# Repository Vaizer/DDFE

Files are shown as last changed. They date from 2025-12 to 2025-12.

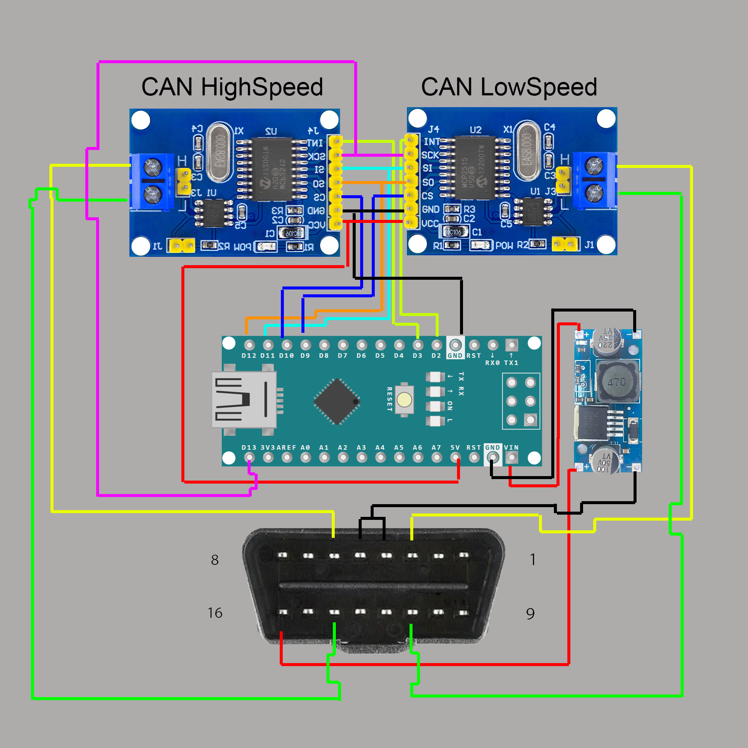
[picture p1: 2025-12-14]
Scheme/Scheme.png

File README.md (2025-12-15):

# DIM's Display Function Extender 
Device for output diagnostic parameters on Volvo P2 dashboard's (DIM) display.\
Using library https://github.com/coryjfowler/MCP_CAN_lib from Cory J Fowler, big thanks for a lot of useful materials to https://github.com/vtl and Volvo-DDD project.

Included sketch mainly aims pre-facelift models (-2004), but all accumulated informartion about other MY are included in sketch for you to try!\
Set up for 2001 Volvo V70XC with B5244T engine and automatic transmission, should work without changes on same configuration (confirmed to work also on B5234T and year 2000 V70).

Pre-facelift cars (-2004) would need getting second OBD2 (or any other) connector **WITH** CAN-L and CAN-H from CEM or it will not work!\
Facelift cars already have CANs on OBD2. Instructions for connecting second OBD2 and device assebly are also included.  \
For now **MY2003-2004 is not guaranteed to work** as I don't have correct IDs or cars to check if it will work with 2002 or other IDs.\
**2000, 2001, 2002, 2005+ tested.**

14 АТФ_Т_найс

## Current supported readouts:
**Engine (ECM):**
- Atmospheric pressure
- Boost pressure
- Intake air temperature
- Mass airflow 
- Battery voltage
- Coolant temperature
- AC pressure
- Speed (kmh)
- Idle fuel trim
- Long-term fuel trim (LTFT) (Low)
- Long-term fuel trim (LTFT) (High)
- Short-term fuel trim (STFT)
- Misfire counter

**Gearbox (TCM):**
- ATF temperature

**Other sensors could be added through getting commands from VIDA log file and DB.**

25 итог

## Controls:
- Short press RESET: changing current parameter (page)
- Long press RESET: disabling output from DDFE on screen (to use display an intended)
Screen enables on short press

## Hardware used:
- Arduino Nano
- 2x MCP2515
- DC-DC converter (12v to 5v)
- OBD2 connector (optional)

## More info about project on my Drive2:
- https://www.drive2.ru/l/712830156913249071/
- https://www.drive2.ru/l/717368116278996470/
- https://www.drive2.ru/l/721407721999439468/

Also check Volvo-P2-informer by drPioneer, inspired by my project: https://github.com/drpioneer/Volvo-P2-informer </br> Same hardware, sketch for facelift models (XC90 2011)

Volvo-DDD by vtl: https://github.com/vtl/volvo-ddd

Not a native english-speaker, not a programmer - sorry for mistakes.

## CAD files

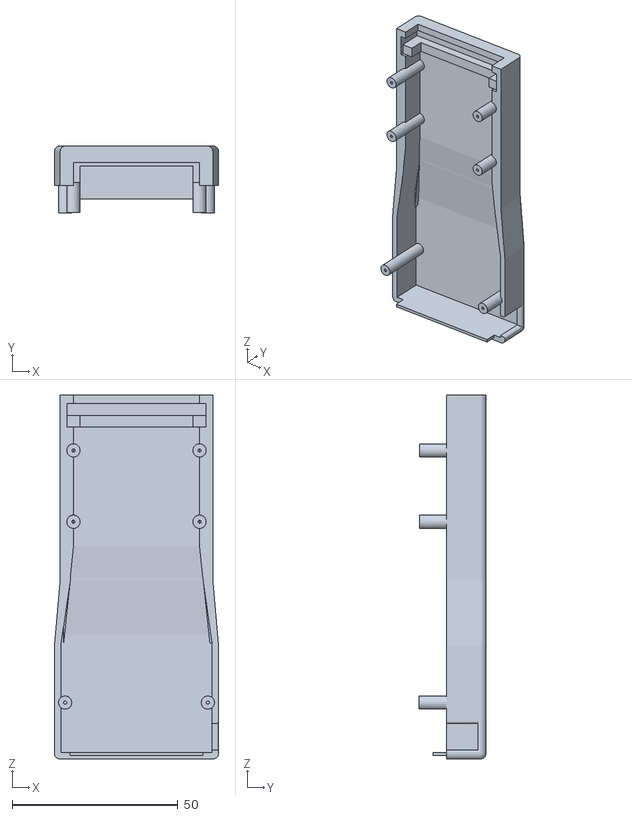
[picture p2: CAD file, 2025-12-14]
Case (3D model)/DDFE_1_2.stl
49.5 x 20.3 x 109.7

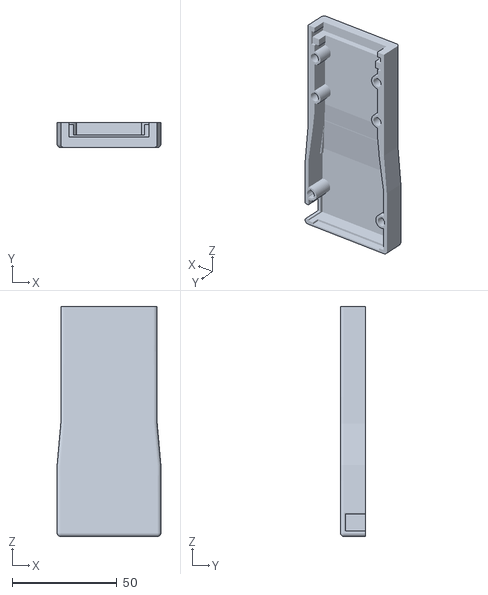
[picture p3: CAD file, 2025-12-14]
Case (3D model)/DDFE_2.stl
49.5 x 12.0 x 109.7

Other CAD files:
Case (3D model)/DDFE_1_1.stl

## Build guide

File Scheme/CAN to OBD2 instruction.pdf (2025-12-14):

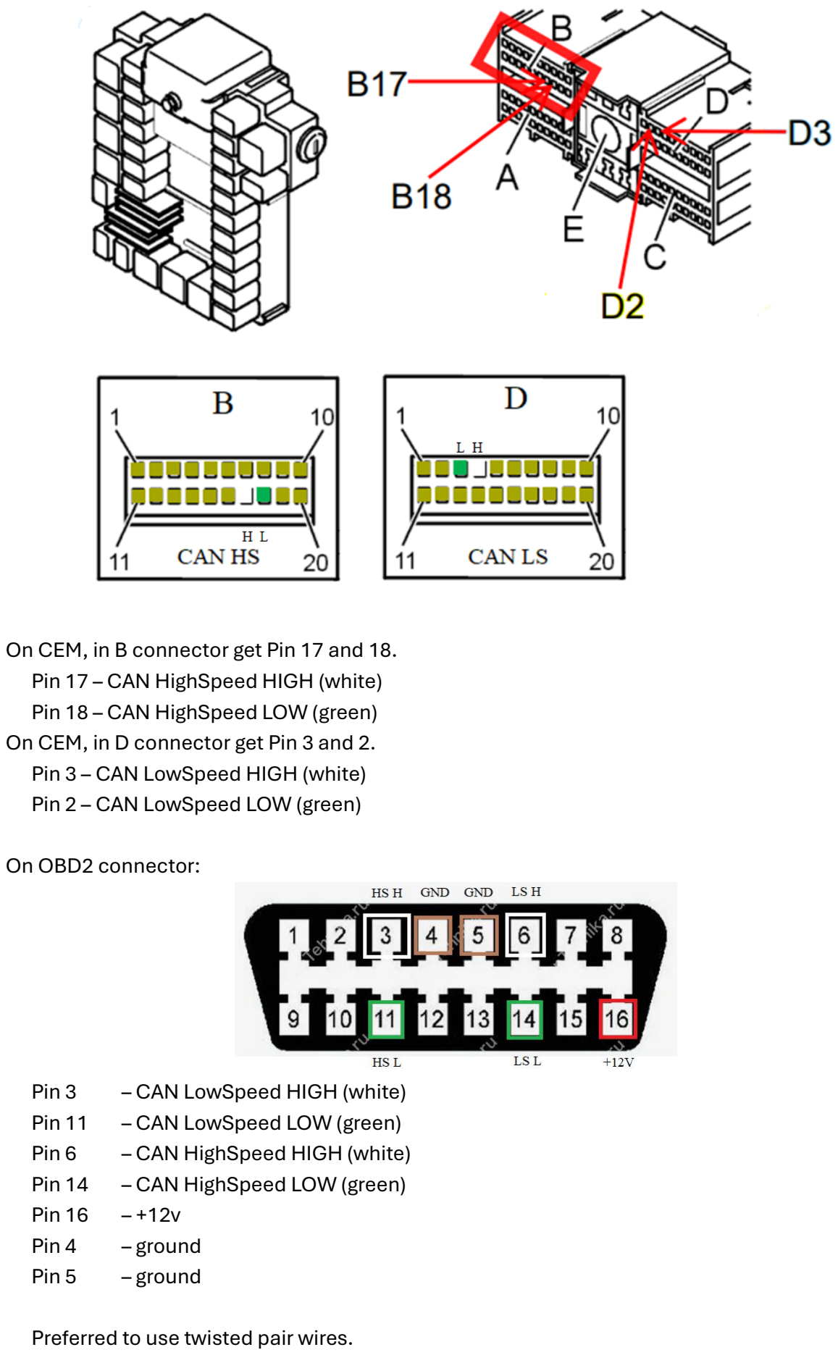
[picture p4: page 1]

On CEM, in B connector get Pin 17 and 18. Pin 17 – CAN HighSpeed HIGH (white) Pin 18 – CAN HighSpeed LOW (green) On CEM, in D connector get Pin 3 and 2. Pin 3 – CAN LowSpeed HIGH (white) Pin 2 – CAN LowSpeed LOW (green)

On OBD2 connector:

Pin 3 | – CAN LowSpeed HIGH (white)
Pin 11 | – CAN LowSpeed LOW (green)
Pin 6 | – CAN HighSpeed HIGH (white)
Pin 14 | – CAN HighSpeed LOW (green)
Pin 16 | – +12v
Pin 4 | – ground
Pin 5 | – ground

Preferred to use twisted pair wires.

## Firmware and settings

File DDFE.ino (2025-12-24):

#include <SPI.h>
#include "mcp_can.h"

// Обозначаем пины подключения CS и INT на шильдах к ардуине к HighSpeed и LowSpeed CAN соответственно
#define CAN_HS_CS_PIN 10
#define CAN_HS_INT    3

#define CAN_LS_CS_PIN 9
#define CAN_LS_INT    2

// Прописываем скорость работы CAN и частоте работы для MCP
#define CAN_HS_SPEED  CAN_250KBPS // Скорость CAN HS для дореста
//#define CAN_HS_SPEED  CAN_500KBPS // Скорость CAN HS для реста 
#define CAN_LS_SPEED  CAN_125KBPS // Скорость CAN LS 

#define MCP_HZ        MCP_16MHZ   // Если частота работы MCP 16MHZ
//#define MCP_HZ        MCP_8MHZ	// Если частота работы MCP 8MHZ

// Прописываем используемые ID (2001г)
#define DIAG_ID     0x000FFFFEUL  // Диагностический id 
#define PHM_ID      0x00400008UL  // id модуля телефона (PHM) (2001)
#define LCD_ID      0x00C0200EUL  // id управления экраном DIM (2001)
#define L_SWITCH_ID 0x8111300AUL  // id левого подрулевого переключателя (2001)
#define TCM_ID      0x80800005UL  // id блока АКПП (TCM) (2001)
#define ECM_ID      0x80800021UL  // id ЭБУ двигателя (ECM) (2001)

#define MASK_ID     0x1FFFFFFFUL  // Маска для 29-битных пакетов
#define NULL_ID     0x00000000UL  // Нулевой ID для лишних фильтров
// Идентификаторы для 2002г
//#define PHM_ID      0x00C00008UL  // id модуля телефона (PHM) (2002)
//#define LCD_ID      0x0220200EUL  // id управления экраном DIM (2002)

// Идентификаторы для 2003-2004г
//#define PHM_ID
//#define LCD_ID      0x02A07428UL  // возможно 2004г id управления экраном DIM

// Идентификаторы для 2005г+ (не точно)
//#define PHM_ID      0x01800008UL  // id модуля телефона (PHM) (рест)
//#define LCD_ID      0x02A0240EUL  // id управления экраном DIM (рест)
//#define L_SWITCH_ID 0x8131726CUL  // id SWM (рест)
//#define TCM_ID      0x81200005UL  // id блока АКПП (TCM) (2001)
//#define ECM_ID      0x81200021UL  // id ЭБУ двигателя (ECM) (2001)


#define CREDITS "      DDFE      by HPM and OLAF " 

// Для изменения количества страниц необходимо изменить значение PAGES_COUNT, скорректировать команды в PAGE_COMMAND, 
// внести ID ответа в PAGE_TARGET_ID, в loop() внутри switch добавить/убрать страницы в соответствии

#define PAGES_COUNT   14            	// Общее количество страниц (параметров)
#define PARAMETER_UPDATE_INTERVAL 300	// Период обновления параметров из CAN (в мс)
#define LONG_PRESS_TIME 500				// Длительность долгого нажатия кнопки RESET (в мс)

// Массив с командами для каждой страницы (команды для B5244T(3)/B5234T, AW55-51, 2001)
unsigned const char PAGE_COMMAND[PAGES_COUNT][8] = {
  { 0xcc, 0x6e, 0xa5, 0x0c, 0x01, 0x00, 0x00, 0x00 }, // Команда на запрос температуры ATF
  { 0xcd, 0x7a, 0xa6, 0x10, 0x07, 0x01, 0x00, 0x00 }, // Команда на запрос атмосферного давления
  { 0xcd, 0x7a, 0xa6, 0x12, 0x9d, 0x01, 0x00, 0x00 }, // Команда на запрос давления наддува
  { 0xcd, 0x7a, 0xa6, 0x10, 0xce, 0x01, 0x00, 0x00 }, // Команда на запрос температуры впускного воздуха
  { 0xcd, 0x7a, 0xa6, 0x10, 0xae, 0x01, 0x00, 0x00 }, // Команда на запрос расхода воздуха MAF
  { 0xcd, 0x7a, 0xa6, 0x10, 0x0a, 0x01, 0x00, 0x00 }, // Команда на запрос напряжения батареи
  { 0xcd, 0x7a, 0xa6, 0x10, 0xd8, 0x01, 0x00, 0x00 }, // Команда на запрос температуры антифриза
  { 0xcd, 0x7a, 0xa6, 0x10, 0x01, 0x01, 0x00, 0x00 }, // Команда на запрос давления в контуре кондиционера
  { 0xcd, 0x7a, 0xa6, 0x11, 0x40, 0x01, 0x00, 0x00 }, // Команда на запрос скорости авто
  { 0xcd, 0x7a, 0xa6, 0x11, 0xd7, 0x01, 0x00, 0x00 }, // Команда на запрос коррекции на холостом ходу
  { 0xcd, 0x7a, 0xa6, 0x11, 0xd9, 0x01, 0x00, 0x00 }, // Команда на запрос долговременной коррекции топлива (L)
  { 0xcd, 0x7a, 0xa6, 0x11, 0xdb, 0x01, 0x00, 0x00 }, // Команда на запрос долговременной коррекции топлива (H)
  { 0xcd, 0x7a, 0xa6, 0x10, 0x70, 0x01, 0x00, 0x00 }, // Команда на запрос кратковременной коррекции топлива
  { 0xcd, 0x7a, 0xa6, 0x10, 0xca, 0x01, 0x00, 0x00 }, // Команда на запрос количества пропусков зажигания
};

/*
// Команды для B5254T2, AW55-51, 2005
unsigned const char PAGE_COMMAND[PAGES_COUNT][8] = {  
  { 0xcc, 0x6e, 0xa5, 0x0c, 0x01, 0x00, 0x00, 0x00 }, // Команда на запрос температуры ATF
  { 0xcd, 0x7a, 0xa6, 0x10, 0x05, 0x01, 0x00, 0x00 }, // Команда на запрос атмосферного давления
  { 0xcd, 0x7a, 0xa6, 0x10, 0xef, 0x01, 0x00, 0x00 }, // Команда на запрос давления наддува
  { 0xcd, 0x7a, 0xa6, 0x10, 0xaf, 0x01, 0x00, 0x00 }, // Команда на запрос температуры впускного воздуха
  { 0xcd, 0x7a, 0xa6, 0x10, 0x9a, 0x01, 0x00, 0x00 }, // Команда на запрос расхода воздуха MAF
  { 0xcd, 0x7a, 0xa6, 0x10, 0x0a, 0x01, 0x00, 0x00 }, // Команда на запрос напряжения батареи (тут не точно)!!
  { 0xcd, 0x7a, 0xa6, 0x10, 0xb8, 0x01, 0x00, 0x00 }, // Команда на запрос температуры антифриза
  { 0xcd, 0x7a, 0xa6, 0x10, 0x01, 0x01, 0x00, 0x00 }, // Команда на запрос давления в контуре кондиционера
  { 0xcd, 0x7a, 0xa6, 0x11, 0x40, 0x01, 0x00, 0x00 }, // Команда на запрос скорости авто (тут не точно)!!
  { 0xcd, 0x7a, 0xa6, 0x11, 0x4c, 0x01, 0x00, 0x00 }, // Команда на запрос долговременной коррекции топлива (L)
  { 0xcd, 0x7a, 0xa6, 0x11, 0x4e, 0x01, 0x00, 0x00 }, // Команда на запрос долговременной коррекции топлива (M)
  { 0xcd, 0x7a, 0xa6, 0x11, 0x50, 0x01, 0x00, 0x00 }, // Команда на запрос долговременной коррекции топлива (H)
  { 0xcd, 0x7a, 0xa6, 0x10, 0x51, 0x01, 0x00, 0x00 }, // Команда на запрос кратковременной коррекции топлива 
  { 0xcd, 0x7a, 0xa6, 0x10, 0xad, 0x01, 0x00, 0x00 }, // Команда на запрос количества пропусков зажигания
};
*/

// Массив с ID для каждой страницы
unsigned const long PAGE_TARGET_ID[PAGES_COUNT] = {
  0x80800005, // ID в ответе на запрос температуры ATF (TCM) (0x00800005) (2001г/дорест)
  0x80800021, // ID в ответе на запрос всего остального (ECM) (0x00800021) (2001г/дорест)
  0x80800021,  
  0x80800021,  
  0x80800021,
  0x80800021,
  0x80800021,
  0x80800021,
  0x80800021,
  0x80800021,
  0x80800021,
  0x80800021,
  0x80800021,
  0x80800021
};
/*
// ID ответов для рестайлинга
unsigned const long PAGE_TARGET_ID[PAGES_COUNT] = {
  0x81200005, // ID в ответе на запрос температуры ATF (TCM) (0x01200005) 
  0x81200021, // ID в ответе на запрос всего остального (ECM) (0x01200021)
  0x81200021,  
  0x81200021,  
  0x81200021,
  0x81200021,  
  0x81200021,
  0x81200021,
  0x81200021,
  0x81200021,
  0x81200021,
  0x81200021,
  0x81200021,
  0x81200021
};
*/

// Эти запросы использовать с LCD_ID для управления дисплеем
unsigned const char EnableLCD_1[8] = { 0xC0, 0x00, 0x00, 0x00, 0x00, 0x00, 0x00, 0x05 };  // Команда на включение экрана (1 из 2) (дорест)
unsigned const char EnableLCD_2[8] = { 0xC0, 0x00, 0x00, 0x00, 0x00, 0x00, 0x00, 0x00 };  // Команда на включение экрана (2 из 2) (дорест)
//unsigned const char EnableLCD_1[8] = { 0xC0, 0x00, 0x00, 0x00, 0x00, 0x00, 0x00, 0x35 };  // Команда на включение экрана (1 из 2) (рест)
//unsigned const char EnableLCD_2[8] = { 0xC0, 0x00, 0x00, 0x00, 0x00, 0x00, 0x00, 0x31 };  // Команда на включение экрана (2 из 2) (рест)
unsigned const char ClearLCD[8]    = { 0xE1, 0xFE, 0x00, 0x00, 0x00, 0x00, 0x00, 0x00 };  // Команда на очистку экрана
unsigned const char DisableLCD[8]  = { 0x00, 0x00, 0x00, 0x00, 0x00, 0x00, 0x00, 0x04 };  // Команда на выключение экрана


// Обозначаем CAN-шины
const MCP_CAN CAN_HS(CAN_HS_CS_PIN);
const MCP_CAN CAN_LS(CAN_LS_CS_PIN);

// Переменные для работы с входящими пакетами
unsigned long inId;         // Хранит ID входящего пакета
unsigned char inLength;     // Хранит длину входящего пакета (всегда одинакова)
unsigned char inBuffer[8];  // Хранит само сообщение в пакете данных

// Переменные для обработки нажатия клавиши RESET
bool          isButtonDown        = false;  // Проверка факта нажатия на кнопку
unsigned long buttonDownTime      = 0;      // Переменная для времени, на сколько фактически кнопка зажата
unsigned long lastParamUpdateTime = 0;      // Время (в мс) с прошлого опроса параметра (влияет в т.ч. на опрос кнопки)
unsigned long currentProgTime     = 0;      // Время (в мс) работы программы на данный момент

int8_t        currentPage         = -1;     // Переменная для хранения текущей страницы


void setup() {
// Serial.begin(115200); 

// Прописываем функции пинов (для прерываний)
//  pinMode(CAN_HS_INT, INPUT_PULLUP);
//  pinMode(CAN_LS_INT, INPUT_PULLUP);

// Инициализируем CAN-шилды
  shieldInit();
//  Serial.println("All Shields init ok!");

  screenEnabler();                            	// Включение и очистка дисплея
  printOnLCD(CREDITS);                        	// Вывод на экран приветствия и отключение после
  delay(1500);
  CAN_LS.sendMsgBuf(LCD_ID, 1, 8, DisableLCD);
}


void loop() {
  buttonCheck(); 								// Функция считывания нажатия кнопки из CAN
// Счетчик переключения страниц по нажатию кнопки RESET подрулевого переключателя 
  if (currentPage == -1) {						// Не отправлять запросы, пока экран выключен
    return;
  }
  currentProgTime = millis();
  if (currentProgTime - lastParamUpdateTime < PARAMETER_UPDATE_INTERVAL) { 	
    return;										// Отправки запроса не будет, пока не пройдет заданное ранее время работы программы
  }
  lastParamUpdateTime = currentProgTime; 		// Сброс счетчика времени работы программы

// Направляем диагностический запрос в CAN_HS
  CAN_HS.sendMsgBuf(DIAG_ID, 1, 8, PAGE_COMMAND[currentPage]);

// Мониторим шину на предмет наличия пакетов в ней
  diagAnswerMonitoring();
}

void shieldInit() {                      		// Функция инициализации CAN-шильдов
// Инициализируем по очереди оба CAN-шилда, с прописыванием их параметров: скорости и частоты кварца
  while (CAN_OK != CAN_HS.begin(MCP_STDEXT, CAN_HS_SPEED, MCP_HZ)) {
//    Serial.println("CAN HighSpeed: Init FAIL!");
    delay(100);
  }
//    Serial.println("CAN HighSpeed: Init OK!");
// Задаем маски и фильтры в MCP для CAN_HS
    CAN_HS.init_Mask(0, 1, MASK_ID);
     CAN_HS.init_Filt(0, 1, ECM_ID);
     CAN_HS.init_Filt(1, 1, TCM_ID);
    CAN_HS.init_Mask(1, 1, MASK_ID);
     CAN_HS.init_Filt(2, 1, DIAG_ID);
     CAN_HS.init_Filt(3, 1, NULL_ID);
     CAN_HS.init_Filt(4, 1, NULL_ID);
     CAN_HS.init_Filt(5, 1, NULL_ID);
    CAN_HS.setMode(MCP_NORMAL);  				// После инициализации переводим в нормальный режим (возможность и приема и передачи сообщения)

  while (CAN_OK != CAN_LS.begin(MCP_STDEXT, CAN_LS_SPEED, MCP_HZ)) {
  //    Serial.println("CAN LowSpeed: Init FAIL!");
    delay(100);
  }
//    Serial.println("CAN LowSpeed: Init OK!");
// Задаем маски и фильтры в MCP для CAN_LS
    CAN_LS.init_Mask(0, 1, MASK_ID);
     CAN_LS.init_Filt(0, 1, L_SWITCH_ID);
     CAN_LS.init_Filt(1, 1, PHM_ID);
    CAN_LS.init_Mask(1, 1, MASK_ID);
     CAN_LS.init_Filt(2, 1, LCD_ID);
     CAN_LS.init_Filt(3, 1, NULL_ID);
     CAN_LS.init_Filt(4, 1, NULL_ID);
     CAN_LS.init_Filt(5, 1, NULL_ID);
    CAN_LS.setMode(MCP_NORMAL);
}

void screenEnabler() {                         	// Функция включения и очистки экрана
  CAN_LS.sendMsgBuf(LCD_ID, 1, 8, EnableLCD_1);
  delay(30);
  CAN_LS.sendMsgBuf(LCD_ID, 1, 8, EnableLCD_2);
  CAN_LS.sendMsgBuf(LCD_ID, 1, 8, ClearLCD);
}

void buttonCheck() {                        	// Функция проверки нажатия кнопки RESET
  while (CAN_LS.checkReceive() == CAN_MSGAVAIL) {
    CAN_LS.readMsgBuf(&inId, &inLength, inBuffer);
    if (!isButtonDown && (inId == L_SWITCH_ID) && (inBuffer[4] == 0xC0)) {		// Сравниваем искомый ID и бит данных (2000-2001)
//    if (!isButtonDown && (inId == L_SWITCH_ID) && (inBuffer[7] == 0xBF)) {	  // Сравниваем искомый ID и бит данных (рест)
      isButtonDown = true;														// Флаг нажатой клавиши
      buttonDownTime = millis();												// Начало отсчета времени нажатия клавиши
    
    } else if (isButtonDown && (inId == L_SWITCH_ID) && (inBuffer[4] == 0x80)) {// Выполнение при отжатии клавиши (2000-2001)
//    } else if (isButtonDown && (inId == L_SWITCH_ID) && (inBuffer[?] == 0x??)){// Выполнение при отжатии клавиши (рест - команда без нажатия кнопки неизвестна)
      isButtonDown = false;
      buttonDownTime = millis() - buttonDownTime;
    
      if ((buttonDownTime >= LONG_PRESS_TIME) && (currentPage >= 0)) {		    // Проверка на долгое нажатие и уже включенный экран
        currentPage = -1;
        CAN_LS.sendMsgBuf(LCD_ID, 1, 8, DisableLCD);						    // Выключение экрана при соответствии											
        lastParamUpdateTime = millis();                                         // Перевод счетчика для дальнейшей работы программы в loop()
      } else if (buttonDownTime < LONG_PRESS_TIME) {                            // Проверка на короткое нажатие
        if (currentPage == -1) {											    // Проверка на выключенный экран
          screenEnabler();													    // Включить экран и перейти на первую страницу
          currentPage = 0;
        } else {															    // Если экран уже включен, то перелистнуть страницу
          currentPage = (currentPage + 1) % PAGES_COUNT;
        }
        lastParamUpdateTime = millis();      
      }
    }
  }
}


void diagAnswerMonitoring() {                  	// Функция мониторинга CAN_HS после отправки диагностического запроса
// Мониторим шину на предмет наличия пакетов в ней
    while (CAN_HS.checkReceive() == CAN_MSGAVAIL) {
    CAN_HS.readMsgBuf(&inId, &inLength, inBuffer);

    if (PAGE_TARGET_ID[currentPage] == inId) {
      long int resInt = 0;
      float resFloat = 0.0;
      switch (currentPage) {
/* Есть вероятность, что при каких-то значениях будут выводиться некорректные данные после операций с байтами inBuffer[] из-за типа данных char (и дальнейших математических операций с ними)
 Как вариант решения - изменить в формулах inBuffer[] на String(inBuffer[]).toInt() для перевода значения в int, после чего операции будут осуществлены только с числовыми переменными, а не с char 
 Это немного замедляет программу, но не должно кардинально на что-либо повлиять */
		  
      case 0:                                           // Первый экран - ATF Temperature
        resInt = 256 * inBuffer[6] + inBuffer[7];
        printOnLCD(String(resInt) + " C ATF Temp");        // Вывод температуры АКПП с подписью на экран
        break;

      case 1:                                           // Второй экран - Atmosphere Pressure
        resInt = inBuffer[5] * 5;
        printOnLCD(String(resInt) + " hPa AtmPres");      // Вывод атмо давления с подписью на экран
        break;

      case 2:                                           // Третий экран - Boost Pressure
        resInt = (256L * inBuffer[5] + inBuffer[6]) / 25.6;
        printOnLCD(String(resInt) + " hPa Boost");        // Вывод давления наддува с подписью на экран
        break;
		
      case 3:                                           // Четвертый экран - Intake Air Temperature
        resInt = inBuffer[5] * 0.75 - 48;
        printOnLCD(String(resInt) + " C IntAirTemp");     // Вывод температуры впускного воздуха с подписью на экран
        break;

      case 4:                                           // Пятый экран - Mass Airflow
        resFloat = (round(256L * inBuffer[5] + inBuffer[6])) * 0.1;
        printOnLCD(String(resFloat) + " kg/h MAF");       // Вывод массового расхода воздуха с подписью на экран
        break;

      case 5:                                           // Шестой экран - Voltage
        resFloat = inBuffer[5] * 0.07;
        printOnLCD(String(resFloat) + " V Voltage");      // Вывод напряжения бортовой сети с подписью на экран
        break;

      case 6:                                           // Седьмой экран - Coolant Temperature
        resInt = inBuffer[5] * 0.75 - 48;
        printOnLCD(String(resInt) + " C CoolantT");       // Вывод температуры охлаждающей жидкости с подписью на экран
        break;

      case 7:                                           // Восьмой экран - AC Pressure
        resFloat = inBuffer[5] * 13.54 - 176;
        printOnLCD(String(resFloat) + " kPa AC");         // Вывод давления контура кондиционера с подписью на экран
        break;

      case 8:                                           // Девятый экран - Vehicle Speed
        resInt = inBuffer[5] * 1.25;
        printOnLCD(String(resInt) + " kmh Speed");        // Вывод скорости авто с подписью на экран
        break;

                                                        // На ресте здесь LTFT (L)
      case 9:                                          // Десятый экран - Idle Fuel Trim
        resFloat = (round(256L * inBuffer[5] + inBuffer[6])) * 0.046875;
        printOnLCD(String(resFloat) + " p. Idle FT");     // Вывод адаптации холостого хода (проценты) с подписью на экран
        break;

                                                        // На ресте здесь LTFT (M)
      case 10:                                          // Одиннадцатый экран - Long Term Fuel Trim (Low Power)
        resFloat = (round(256L * inBuffer[5] + inBuffer[6])) * 0.00003052;
        printOnLCD(String(resFloat) + " LTFT (L)");       // Вывод долгосрочной коррекции при низкой нагрузке с подписью на экран
        break;

      case 11:                                          // Двенадцатый экран - Long Term Fuel Trim (High Power)
        resFloat = (round(256L * inBuffer[5] + inBuffer[6])) * 0.00003052;
        printOnLCD(String(resFloat) + " LTFT (H)");       // Вывод долгосрочной коррекции при высокой нагрузке с подписью на экран
        break;

      case 12:                                          // Тринадцатый экран - ShortTermCorrection
        resFloat = ((round(256L * inBuffer[5] + inBuffer[6])) * 2) / 65535.0;
        printOnLCD(String(resFloat) + " STFT");           // Вывод краткосрочной коррекции с подписью на экран
        break;

      case 13:                                          // Четырнадцатый экран - MisfireCounter
        resInt = 256L * inBuffer[5] + inBuffer[6];
        printOnLCD(String(resInt) + " Misfires");         // Вывод количество пропусков зажигания с подписью на экран
        break;

      default:                                          // Экран ошибки
        printOnLCD("ERR PG " + String(currentPage));
        break;
      }
    }
  }
}

void printOnLCD(String input) {                	// Передча строки на вход функции, она переделает её под нужные пакеты и подаст на вход DIM для вывода на экран
  if (input.length() > 32)
    input = "Message length  too long";        	// На всякий случай проверка на превышение длины сообщения

  while (input.length() < 32)                   // Заполняем сообщение до максимальных 32 символов пробелами
    input += " ";

  unsigned char msg[5][8] = {                   // Заполнение массива на вывод полного сообщения на 32 символа (2х16) в требуемом DIM'ом виде 
    { 0xA7, 0x00, input[0], input[1], input[2], input[3], input[4], input[5] },
    { 0x21, input[6], input[7], input[8], input[9], input[10], input[11], input[12] },
    { 0x22, input[13], input[14], input[15], input[16], input[17], input[18], input[19] },
    { 0x23, input[20], input[21], input[22], input[23], input[24], input[25], input[26] },
    { 0x65, input[27], input[28], input[29], input[30], input[31], 0x00, 0x00 }
  };

  CAN_LS.sendMsgBuf(LCD_ID, 1, 8, ClearLCD);	// Очистка экрана перед выводом нового сообщения во избежание появления символов от предыдущего сообщения
  delay(10);

  for (int i = 0; i < 5; i++) {                	// Вывод сообщения на экран (из массива) с учетом задержки между пакетами в 30мс
    CAN_LS.sendMsgBuf(PHM_ID, 1, 8, msg[i]);
    delay(10);
  }
}

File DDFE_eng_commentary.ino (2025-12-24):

#include <SPI.h>
#include "mcp_can.h"

// Define pins for CS and INT from shields to arduino on HighSpeed and LowSpeed CAN
#define CAN_HS_CS_PIN 10
#define CAN_HS_INT    3

#define CAN_LS_CS_PIN 9
#define CAN_LS_INT    2

// Define CAN speed and frequency for MCP
#define CAN_HS_SPEED  CAN_250KBPS // CAN HS speed for pre-facelift (-2004)
//#define CAN_HS_SPEED  CAN_500KBPS // CAN HS speed for facelift (2005+)
#define CAN_LS_SPEED  CAN_125KBPS // CAN LS speed

#define MCP_HZ        MCP_16MHZ   // If MCP have 16MHZ quartz
//#define MCP_HZ        MCP_8MHZ	// If MCP have 8MHZ quartz

// Define needed IDs (2000-2001)
#define DIAG_ID     0x000FFFFEUL  // Diagnostics id 
#define PHM_ID      0x00400008UL  // id for phone module (PHM) (2001)
#define LCD_ID      0x00C0200EUL  // id for screen control on DIM (2001)
#define L_SWITCH_ID 0x8111300AUL  // id for left steering column switch (2001)
#define TCM_ID      0x80800005UL  // id for transmission module (TCM) (2001)
#define ECM_ID      0x80800021UL  // id for engine control unit (ECM) (2001)

#define MASK_ID     0x1FFFFFFFUL  // Mask for 29-bit packets
#define NULL_ID     0x00000000UL  // Null ID for excess filters

// Define IDs (2002)
//#define PHM_ID      0x00C00008UL  // id for phone module (PHM) (2002)
//#define LCD_ID      0x0220200EUL  // id for screen control on DIM (2002)

// Define IDs (2003-2004)
//#define PHM_ID
//#define LCD_ID      0x02A07428UL  // probably 2004 id for screen control on DIM

// Define IDs (2005+) 
//#define PHM_ID      0x01800008UL  // id for phone module (PHM) (FL)
//#define LCD_ID      0x02A0240EUL  // id for screen control on DIM (FL)
//#define L_SWITCH_ID 0x8131726CUL  // id for left steering column switch (FL)
//#define TCM_ID      0x81200005UL  // id transmission module (TCM) (FL)
//#define ECM_ID      0x81200021UL  // id for engine control unit (ECM) (FL)


#define CREDITS "      DDFE      by HPM and OLAF " 

/*  If you need to change output parameters - change PAGES_COUNT number, in PAGE_COMMAND delete\comment commands that you don't need 
    correct PAGE_TARGER_ID, and diagAnswerMonitoring */

#define PAGES_COUNT   14            	// Number of pages (parameters)
#define PARAMETER_UPDATE_INTERVAL 300	// Parameter update period (in ms)
#define LONG_PRESS_TIME 500				    // Duration of long press RESET (in ms)

// Array with commands for every page (for B5244T(3)/B5234T, AW55-51, 2000-2001)
unsigned const char PAGE_COMMAND[PAGES_COUNT][8] = {
  { 0xcc, 0x6e, 0xa5, 0x0c, 0x01, 0x00, 0x00, 0x00 }, // Command for ATF temperature
  { 0xcd, 0x7a, 0xa6, 0x10, 0x07, 0x01, 0x00, 0x00 }, // Command for atmospheric pressure
  { 0xcd, 0x7a, 0xa6, 0x12, 0x9d, 0x01, 0x00, 0x00 }, // Command for boost pressure
  { 0xcd, 0x7a, 0xa6, 0x10, 0xce, 0x01, 0x00, 0x00 }, // Command for intake temperature
  { 0xcd, 0x7a, 0xa6, 0x10, 0xae, 0x01, 0x00, 0x00 }, // Command for mass airflow
  { 0xcd, 0x7a, 0xa6, 0x10, 0x0a, 0x01, 0x00, 0x00 }, // Command for battery voltage
  { 0xcd, 0x7a, 0xa6, 0x10, 0xd8, 0x01, 0x00, 0x00 }, // Command for coolant temperature
  { 0xcd, 0x7a, 0xa6, 0x10, 0x01, 0x01, 0x00, 0x00 }, // Command for AC pressure
  { 0xcd, 0x7a, 0xa6, 0x11, 0x40, 0x01, 0x00, 0x00 }, // Command for vehicle speed
  { 0xcd, 0x7a, 0xa6, 0x11, 0xd7, 0x01, 0x00, 0x00 }, // Command for idle fuel trim
  { 0xcd, 0x7a, 0xa6, 0x11, 0xd9, 0x01, 0x00, 0x00 }, // Command for long-time fuel trim (L)
  { 0xcd, 0x7a, 0xa6, 0x11, 0xdb, 0x01, 0x00, 0x00 }, // Command for long-time fuel trim (H)
  { 0xcd, 0x7a, 0xa6, 0x10, 0x70, 0x01, 0x00, 0x00 }, // Command for short-time fuel trim
  { 0xcd, 0x7a, 0xa6, 0x10, 0xca, 0x01, 0x00, 0x00 }, // Command for misfires count
};

/*
// Commands for B5254T2, AW55-51, 2005
unsigned const char PAGE_COMMAND[PAGES_COUNT][8] = {  
  { 0xcc, 0x6e, 0xa5, 0x0c, 0x01, 0x00, 0x00, 0x00 }, // Command for ATF temperature
  { 0xcd, 0x7a, 0xa6, 0x10, 0x05, 0x01, 0x00, 0x00 }, // Command for atmospheric pressure
  { 0xcd, 0x7a, 0xa6, 0x10, 0xef, 0x01, 0x00, 0x00 }, // Command for boost pressure
  { 0xcd, 0x7a, 0xa6, 0x10, 0xaf, 0x01, 0x00, 0x00 }, // Command for intake temperature
  { 0xcd, 0x7a, 0xa6, 0x10, 0x9a, 0x01, 0x00, 0x00 }, // Command for mass airflow
  { 0xcd, 0x7a, 0xa6, 0x10, 0x0a, 0x01, 0x00, 0x00 }, // Command for battery voltage (not sure)
  { 0xcd, 0x7a, 0xa6, 0x10, 0xb8, 0x01, 0x00, 0x00 }, // Command for coolant temperature
  { 0xcd, 0x7a, 0xa6, 0x10, 0x01, 0x01, 0x00, 0x00 }, // Command for AC pressure
  { 0xcd, 0x7a, 0xa6, 0x11, 0x40, 0x01, 0x00, 0x00 }, // Command for vehicle speed (not sure)
  { 0xcd, 0x7a, 0xa6, 0x11, 0x4c, 0x01, 0x00, 0x00 }, // Command for long-time fuel trim (L)
  { 0xcd, 0x7a, 0xa6, 0x11, 0x4e, 0x01, 0x00, 0x00 }, // Command for long-time fuel trim (M)
  { 0xcd, 0x7a, 0xa6, 0x11, 0x50, 0x01, 0x00, 0x00 }, // Command for long-time fuel trim (H)
  { 0xcd, 0x7a, 0xa6, 0x10, 0x51, 0x01, 0x00, 0x00 }, // Command for short-time fuel trim 
  { 0xcd, 0x7a, 0xa6, 0x10, 0xad, 0x01, 0x00, 0x00 }, // Command for misfires count
};
*/

// Array of IDs for every page (pre-fl/2000-2001)
unsigned const long PAGE_TARGET_ID[PAGES_COUNT] = {
  0x80800005, // ID for TCM (0x00800005) (2000-2001/pre-fl)
  0x80800021, // ID for ECM (0x00800021) (2000-2001/pre-fl)
  0x80800021,  
  0x80800021,  
  0x80800021,
  0x80800021,
  0x80800021,
  0x80800021,
  0x80800021,
  0x80800021,
  0x80800021,
  0x80800021,
  0x80800021,
  0x80800021
};
/*
// Array of IDs for every page (facelift/2005+)
unsigned const long PAGE_TARGET_ID[PAGES_COUNT] = {
  0x81200005, // ID for TCM (0x01200005) 
  0x81200021, // ID for ECM (0x01200021)
  0x81200021,  
  0x81200021,  
  0x81200021,
  0x81200021,  
  0x81200021,
  0x81200021,
  0x81200021,
  0x81200021,
  0x81200021,
  0x81200021,
  0x81200021,
  0x81200021
};
*/

// Commands for LCD_ID to manage DIM's display
unsigned const char EnableLCD_1[8] = { 0xC0, 0x00, 0x00, 0x00, 0x00, 0x00, 0x00, 0x05 };  // Command to turn on screen (1 из 2) (pre-fl)
unsigned const char EnableLCD_2[8] = { 0xC0, 0x00, 0x00, 0x00, 0x00, 0x00, 0x00, 0x00 };  // Command to turn on screen (2 из 2) (pre-fl)
//unsigned const char EnableLCD_1[8] = { 0xC0, 0x00, 0x00, 0x00, 0x00, 0x00, 0x00, 0x35 };  // Command to turn on screen (1 из 2) (fl)
//unsigned const char EnableLCD_2[8] = { 0xC0, 0x00, 0x00, 0x00, 0x00, 0x00, 0x00, 0x31 };  // Command to turn on screen (2 из 2) (fl)
unsigned const char ClearLCD[8]    = { 0xE1, 0xFE, 0x00, 0x00, 0x00, 0x00, 0x00, 0x00 };  // Command to clear screen
unsigned const char DisableLCD[8]  = { 0x00, 0x00, 0x00, 0x00, 0x00, 0x00, 0x00, 0x04 };  // Commnad to disable screen


// Define CAN on MCP
const MCP_CAN CAN_HS(CAN_HS_CS_PIN);
const MCP_CAN CAN_LS(CAN_LS_CS_PIN);

// Variables for in- packets
unsigned long inId;         // Contains ID of in- packet
unsigned char inLength;     // Contains length of in- packet (always the same)
unsigned char inBuffer[8];  // Contains message itself
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

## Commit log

2025-12-14 Add files via upload
    DDFE v1.2
    RESET button now changes output parameter (page) on short press and disable output on display on long press
    [DDFE.ino]
2025-12-23 RESET button reading improved, formulas optimised, minor changes
    - parameter update period set on fixed time instead of program cycles (ticks) -> some variables also deleted and added because of that
    - long press time now put in "define" section
    - shield init corrected (will try until success)
    - formulas on parameter output simplified (idk why it didn't work like that earlier, so it was slower but kinda more correct). Hope it wouldn't break anything
    - changed delay between messages to DIM from 30ms to 10ms drastically improving RESET button readings. It was widely known, that it won't work with less delay but...it works flawlessly
    - minor changes
    [DDFE.ino]
2025-12-24 Update DDFE.ino
    Correction of ATF temperature formula. Now minus temperatures should display correctly
    [DDFE.ino]
2025-12-24 Update DDFE_eng_commentary.ino
    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
    [DDFE_eng_commentary.ino]
